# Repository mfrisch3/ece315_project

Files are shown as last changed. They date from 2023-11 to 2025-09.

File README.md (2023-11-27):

# PSoC&trade; 4: empty application template

This is a minimal starter application template for PSoC&trade; 4 devices.

[View this README on GitHub.](https://github.com/Infineon/mtb-example-psoc4-empty-app)

[Provide feedback on this code example.](https://cypress.co1.qualtrics.com/jfe/form/SV_1NTns53sK2yiljn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)

## Requirements

- [ModusToolbox&trade; software](https://www.cypress.com/products/modustoolbox-software-environment) v2.4 or later

  **Note:** This code example version requires ModusToolbox&trade; software version 2.4 or later and is not backward compatible with v2.3 or older versions.

- Board support package (BSP) minimum required version: 2.0.0
- Programming language: C
- Associated parts: [PSoC&trade; 4000S](https://www.cypress.com/documentation/datasheets/psoc-4-psoc-4000s-family-datasheet-programmable-system-chip-psoc), [PSoC&trade; 4100S](https://www.cypress.com/documentation/datasheets/psoc-4-psoc-4100s-family-datasheet-programmable-system-chip-psoc), [PSoC&trade; 4100S Plus](https://www.cypress.com/documentation/datasheets/psoc-4-psoc-4100s-plus-datasheet-programmable-system-chip-psoc), [PSoC&trade; 4500S](https://www.cypress.com/documentation/datasheets/psoc-4-psoc-4500s-datasheet-programmable-system-chip-psoc), and [PSoC&trade; 4100S Max](https://www.cypress.com/documentation/datasheets/psoc-4-psoc-4100s-max-datasheet-programmable-system-chip-psoc)

## Supported toolchains (make variable 'TOOLCHAIN')

- GNU Arm® embedded compiler v10.3.1 (`GCC_ARM`) - Default value of `TOOLCHAIN`
- Arm&reg; compiler v6.13 (`ARM`)
- IAR C/C++ compiler v8.42.2 (`IAR`)

## Supported kits (make variable 'TARGET')

- [PSoC&trade; 4100S Max pioneer kit](https://www.cypress.com/CY8CKIT-041s-max) (CY8CKIT-041S-MAX) - Default value of `TARGET`
- [PSoC&trade; 4100S Plus prototyping kit](https://www.cypress.com/CY8CKIT-149) (CY8CKIT-149)
- [PSoC&trade; 4100S CAPSENSE&trade; pioneer kit](https://www.cypress.com/CY8CKIT-041-41xx) (CY8CKIT-041-41XX)
- [PSoC&trade; 4000S CAPSENSE&trade; prototyping kit](https://www.cypress.com/CY8CKIT-145-40xx) (CY8CKIT-145-40XX)
- [PSoC&trade; 4500S pioneer kit](https://www.cypress.com/CY8CKIT-045S) (CY8CKIT-045S)

## Hardware setup

This example uses the board's default configuration. See the kit user guide to ensure that the board is configured correctly.

**Note:** The PSoC&trade; 4 kits ship with KitProg2 installed. The ModusToolbox&trade; software requires KitProg3. Before using this code example, make sure that the board is upgraded to KitProg3. The tool and instructions are available in the [Firmware Loader](https://github.com/Infineon/Firmware-loader) GitHub repository. If you do not upgrade, you will see an error like "unable to find CMSIS-DAP device" or "KitProg firmware is out of date".

## Software setup

This example requires no additional software or tools.
<br>

## Related resources

Resources  | Links
-----------|----------------------------------
Application notes | [AN79953](https://www.cypress.com/AN79953) – Getting started with PSoC&trade; 4
Code examples| [Using ModusToolbox&trade; software](https://github.com/Infineon/Code-Examples-for-ModusToolbox-Software) on GitHub <br> [Using PSoC&trade; Creator](https://www.cypress.com/documentation/code-examples/psoc-345-code-examples)
Device documentation | [PSoC&trade; 4 datasheets](https://www.cypress.com/search/all/PSOC%204%20datasheets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) <br>[PSoC&trade; 4 technical reference manuals](https://www.cypress.com/search/all/PSoC%204%20Technical%20Reference%20Manual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)
Development kits | Visit www.cypress.com/microcontrollers-mcus-kits and use the options in the **Select your kit** section to filter kits by *Product family* or *Features*.
Libraries on GitHub | [mtb-pdl-cat2](https://github.com/Infineon/mtb-pdl-cat2) – PSoC&trade; 4 peripheral driver library (PDL)<br> [mtb-hal-cat2](https://github.com/Infineon/mtb-hal-cat2) – Hardware abstraction layer (HAL) library
Tools  | [Eclipse IDE for ModusToolbox&trade; software](https://www.cypress.com/modustoolbox) – ModusToolbox&trade; software is a collection of easy-to-use software and tools enabling rapid development with Infineon MCUs, covering applications from embedded sense and control to wireless and cloud-connected systems using AIROC&trade; Wi-Fi and Bluetooth® connectivity devices. <br> [PSoC&trade; Creator](https://www.cypress.com/products/psoc-creator-integrated-design-environment-ide) – IDE for PSoC&trade; and FM0+ MCU development

<br>

## Other resources

Cypress provides a wealth of data at www.cypress.com to help you select the right device, and quickly and effectively integrate it into your design.

## Document history

Document title: *CE230705 - PSoC&trade; 4: empty application template*

Version | Description of change
------- | ---------------------
 1.0.0   | New code example
 2.0.0   | Major update to support ModusToolbox&trade; software v2.2, added support for new kits<br> This version is not backward compatible with ModusToolbox&trade; software v2.1
 2.1.0   | Added support for new kits

<br>

---------------------------------------------------------

© Cypress Semiconductor Corporation, 2020-2021. This document is the property of Cypress Semiconductor Corporation, an Infineon Technologies company, and its affiliates ("Cypress").  This document, including any software or firmware included or referenced in this document ("Software"), is owned by Cypress under the intellectual property laws and treaties of the United States and other countries worldwide.  Cypress reserves all rights under such laws and treaties and does not, except as specifically stated in this paragraph, grant any license under its patents, copyrights, trademarks, or other intellectual property rights.  If the Software is not accompanied by a license agreement and you do not otherwise have a written agreement with Cypress governing the use of the Software, then Cypress hereby grants you a personal, non-exclusive, nontransferable license (without the right to sublicense) (1) under its copyright rights in the Software (a) for Software provided in source code form, to modify and reproduce the Software solely for use with Cypress hardware products, only internally within your organization, and (b) to distribute the Software in binary code form externally to end users (either directly or indirectly through resellers and distributors), solely for use on Cypress hardware product units, and (2) under those claims of Cypress’s patents that are infringed by the Software (as provided by Cypress, unmodified) to make, use, distribute, and import the Software solely for use with Cypress hardware products.  Any other use, reproduction, modification, translation, or compilation of the Software is prohibited.
<br>
TO THE EXTENT PERMITTED BY APPLICABLE LAW, CYPRESS MAKES NO WARRANTY OF ANY KIND, EXPRESS OR IMPLIED, WITH REGARD TO THIS DOCUMENT OR ANY SOFTWARE OR ACCOMPANYING HARDWARE, INCLUDING, BUT NOT LIMITED TO, THE IMPLIED WARRANTIES OF MERCHANTABILITY AND FITNESS FOR A PARTICULAR PURPOSE.  No computing device can be absolutely secure.  Therefore, despite security measures implemented in Cypress hardware or software products, Cypress shall have no liability arising out of any security breach, such as unauthorized access to or use of a Cypress product. CYPRESS DOES NOT REPRESENT, WARRANT, OR GUARANTEE THAT CYPRESS PRODUCTS, OR SYSTEMS CREATED USING CYPRESS PRODUCTS, WILL BE FREE FROM CORRUPTION, ATTACK, VIRUSES, INTERFERENCE, HACKING, DATA LOSS OR THEFT, OR OTHER SECURITY INTRUSION (collectively, "Security Breach").  Cypress disclaims any liability relating to any Security Breach, and you shall and hereby do release Cypress from any claim, damage, or other liability arising from any Security Breach.  In addition, the products described in these materials may contain design defects or errors known as errata which may cause the product to deviate from published specifications. To the extent permitted by applicable law, Cypress reserves the right to make changes to this document without further notice. Cypress does not assume any liability arising out of the application or use of any product or circuit described in this document. Any information provided in this document, including any sample design information or programming code, is provided only for reference purposes.  It is the responsibility of the user of this document to properly design, program, and test the functionality and safety of any application made of this information and any resulting product.  "High-Risk Device" means any device or system whose failure could cause personal injury, death, or property damage.  Examples of High-Risk Devices are weapons, nuclear installations, surgical implants, and other medical devices.  "Critical Component" means any component of a High-Risk Device whose failure to perform can be reasonably expected to cause, directly or indirectly, the failure of the High-Risk Device, or to affect its safety or effectiveness.  Cypress is not liable, in whole or in part, and you shall and hereby do release Cypress from any claim, damage, or other liability arising from any use of a Cypress product as a Critical Component in a High-Risk Device. You shall indemnify and hold Cypress, including its affiliates, and its directors, officers, employees, agents, distributors, and assigns harmless from and against all claims, costs, damages, and expenses, arising out of any claim, including claims for product liability, personal injury or death, or property damage arising from any use of a Cypress product as a Critical Component in a High-Risk Device. Cypress products are not intended or authorized for use as a Critical Component in any High-Risk Device except to the limited extent that (i) Cypress’s published data sheet for the product explicitly states Cypress has qualified the product for use in a specific High-Risk Device, or (ii) Cypress has given you advance written authorization to use the product as a Critical Component in the specific High-Risk Device and you have signed a separate indemnification agreement.
<br>
Cypress, the Cypress logo, and combinations thereof, WICED, ModusToolbox, PSoC, CapSense, EZ-USB, F-RAM, and Traveo are trademarks or registered trademarks of Cypress or a subsidiary of Cypress in the United States or in other countries. For a more complete list of Cypress trademarks, visit cypress.com. Other names and brands may be claimed as property of their respective owners.

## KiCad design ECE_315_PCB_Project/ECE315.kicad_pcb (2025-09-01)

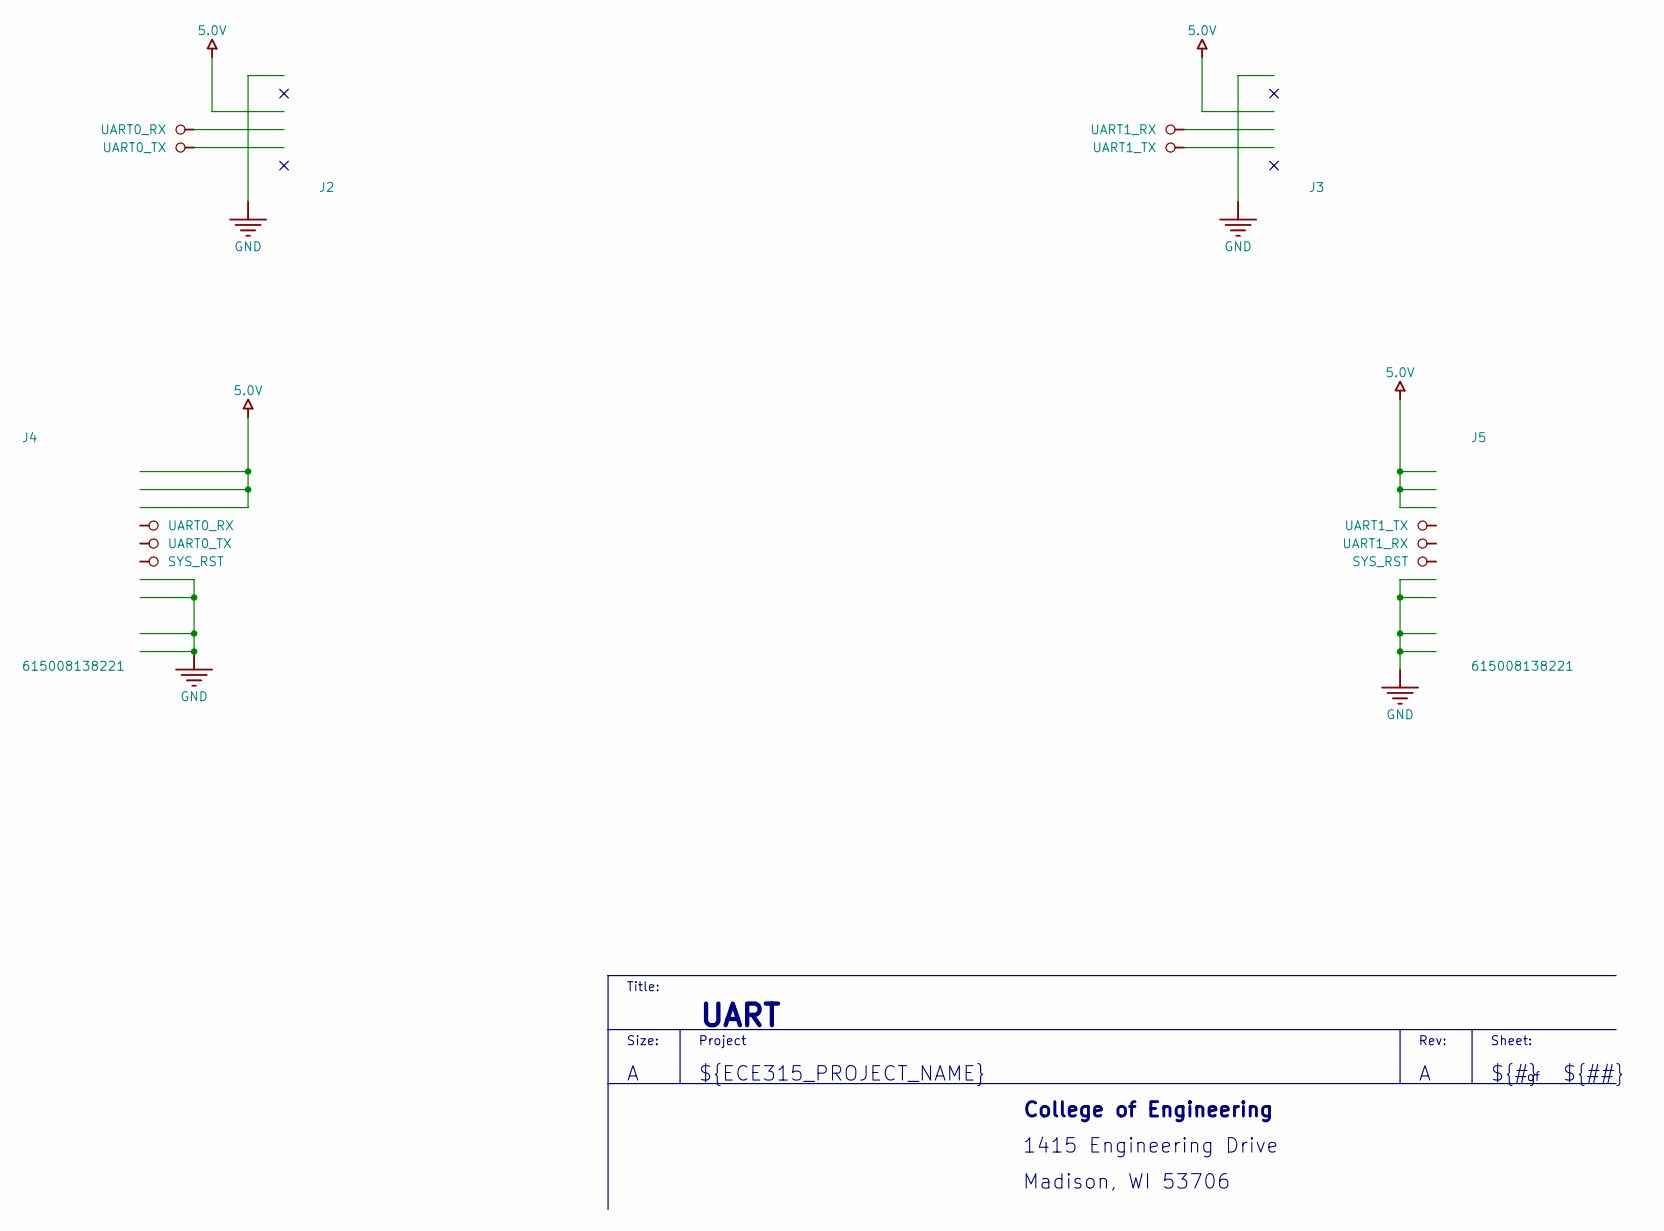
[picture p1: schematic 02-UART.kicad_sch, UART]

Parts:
J2, J3: HDR1X6; VOLTAGE RATING 250V; FLAMMABILITY RATING UL94 V-0; MANUFACTURER PART NUMBE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 PPPC061LGBN-RC
J4, J5: 615008138221; WITHSTANDING VOLTAGE 1000VAC; WORKING VOLTAGE 120VAC; PART NUMBER 615008138221

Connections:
5.0V: J2.3, J3.3, J4.1, J4.2, J4.3, J5.1, J5.2, J5.3; also elsewhere on the board
GND: J2.1, J3.1, J4.7, J4.8, J4.S1, J4.S2, J5.7, J5.8, J5.S1, J5.S2; also elsewhere on the board
SYS_RST: J4.6, J5.6; also elsewhere on the board
UART0_RX: J2.4, J4.4; also elsewhere on the board
UART0_TX: J2.5, J4.5; also elsewhere on the board
UART1_RX: J3.4, J5.5; also elsewhere on the board
UART1_TX: J3.5, J5.4; also elsewhere on the board

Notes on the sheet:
Rev:
Sheet:
${REVISION}
Size:
${TITLE}
${#}
Project
College of Engineering
Title:
${ECE315_PROJECT_NAME}
1415 Engineering Drive
Madison, WI 53706
${##}

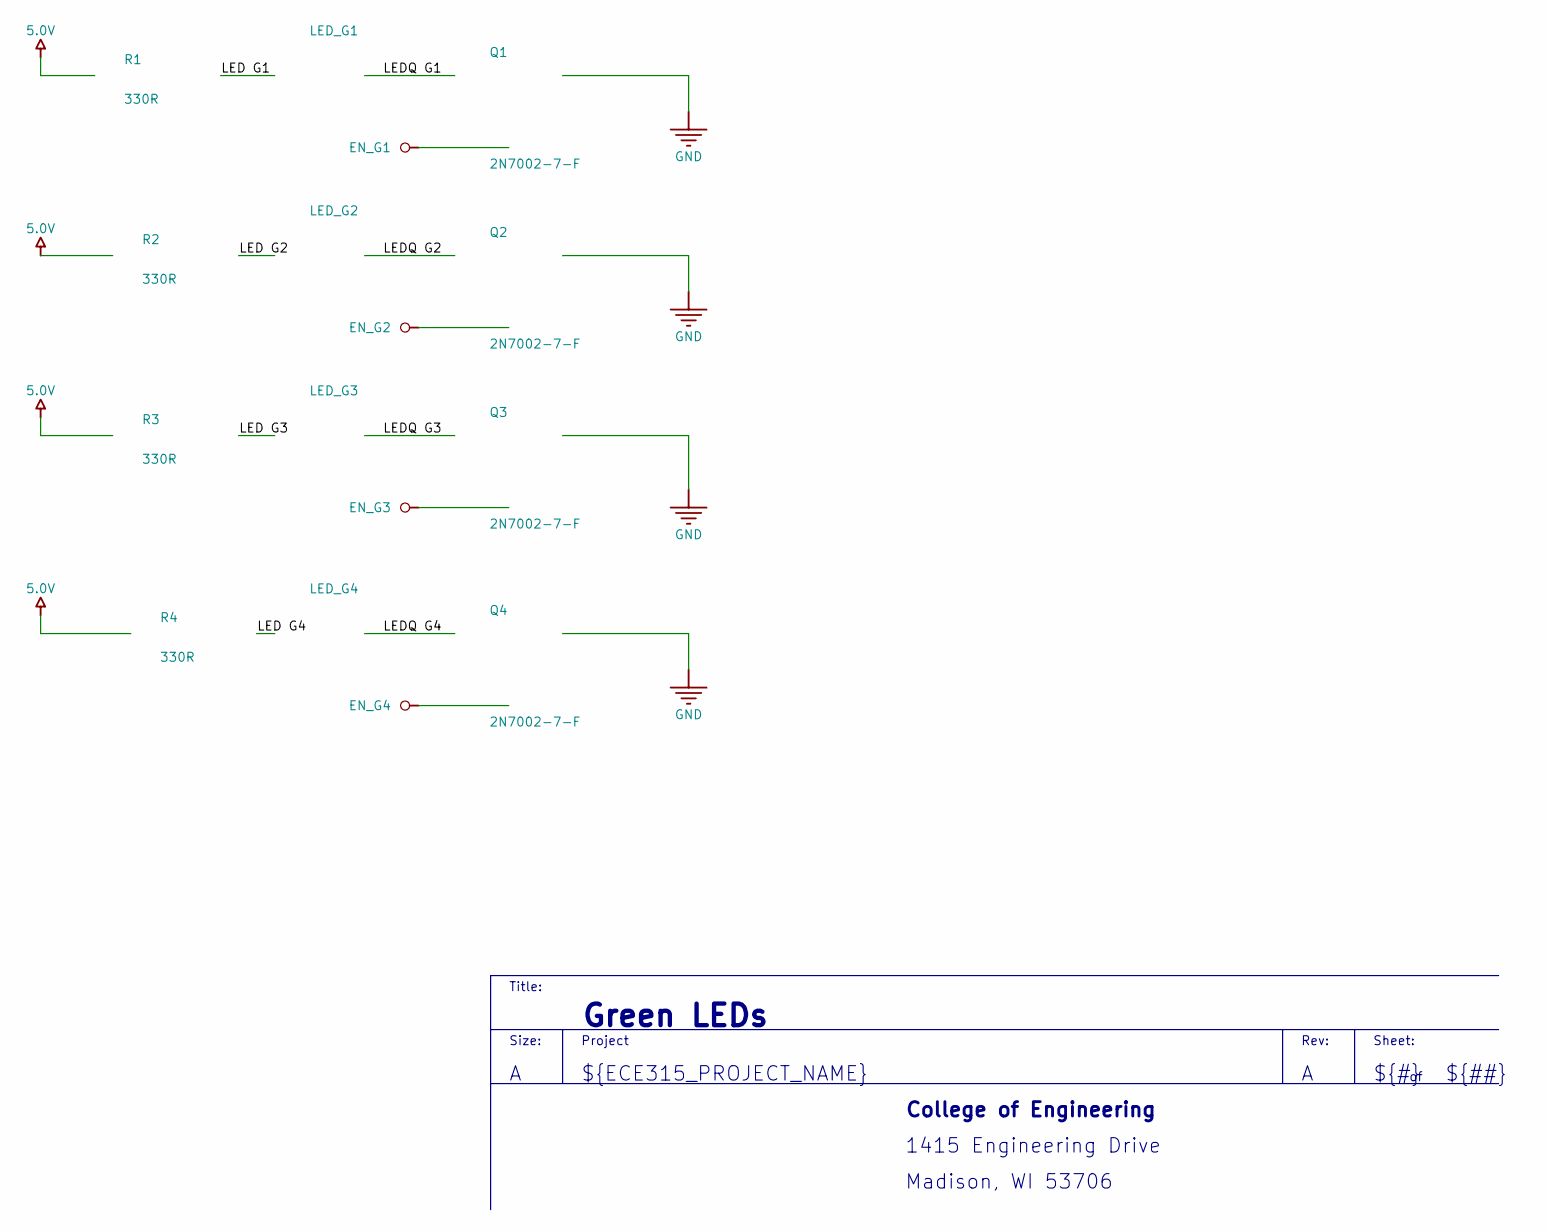
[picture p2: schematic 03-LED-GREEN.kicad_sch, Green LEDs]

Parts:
LED_G1, LED_G2, LED_G3, LED_G4: 150120GS75000; WL-SMCW_1206_150120xx75000; REVERSE VOLTAGE 5V; FORWARD VOLTAGE 3.2V; MANUFACTURER PART NUMBER 150120GS75000
Q1, Q2, Q3, Q4: 2N7002-7-F; FP-SOT23-MFG; CURRENT RATING 115mA; VOLTAGE RATING (DC) 60V
R1, R2, R3, R4: 330R; FP-CRCW1206-e3-IPC_A; VOLTAGE RATING 200V; VOLTAGE RATING (DC) 200V

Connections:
5.0V: R1.1, R2.1, R3.1, R4.1; also elsewhere on the board
EN_G1: Q1.1 (G); also elsewhere on the board
EN_G2: Q2.1 (G); also elsewhere on the board
EN_G3: Q3.1 (G); also elsewhere on the board
EN_G4: Q4.1 (G); also elsewhere on the board
GND: Q1.2 (S), Q2.2 (S), Q3.2 (S), Q4.2 (S); also elsewhere on the board
LED G1: LED_G1.2 (A), R1.2
LED G2: LED_G2.2 (A), R2.2
LED G3: LED_G3.2 (A), R3.2
LED G4: LED_G4.2 (A), R4.2
LEDQ G1: LED_G1.1 (K), Q1.3 (D)
LEDQ G2: LED_G2.1 (K), Q2.3 (D)
LEDQ G3: LED_G3.1 (K), Q3.3 (D)
LEDQ G4: LED_G4.1 (K), Q4.3 (D)

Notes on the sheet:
${ECE315_PROJECT_NAME}
College of Engineering
${TITLE}
Size:
${##}
${#}
Rev:
1415 Engineering Drive
Madison, WI 53706
Sheet:
${REVISION}
Title:
Project

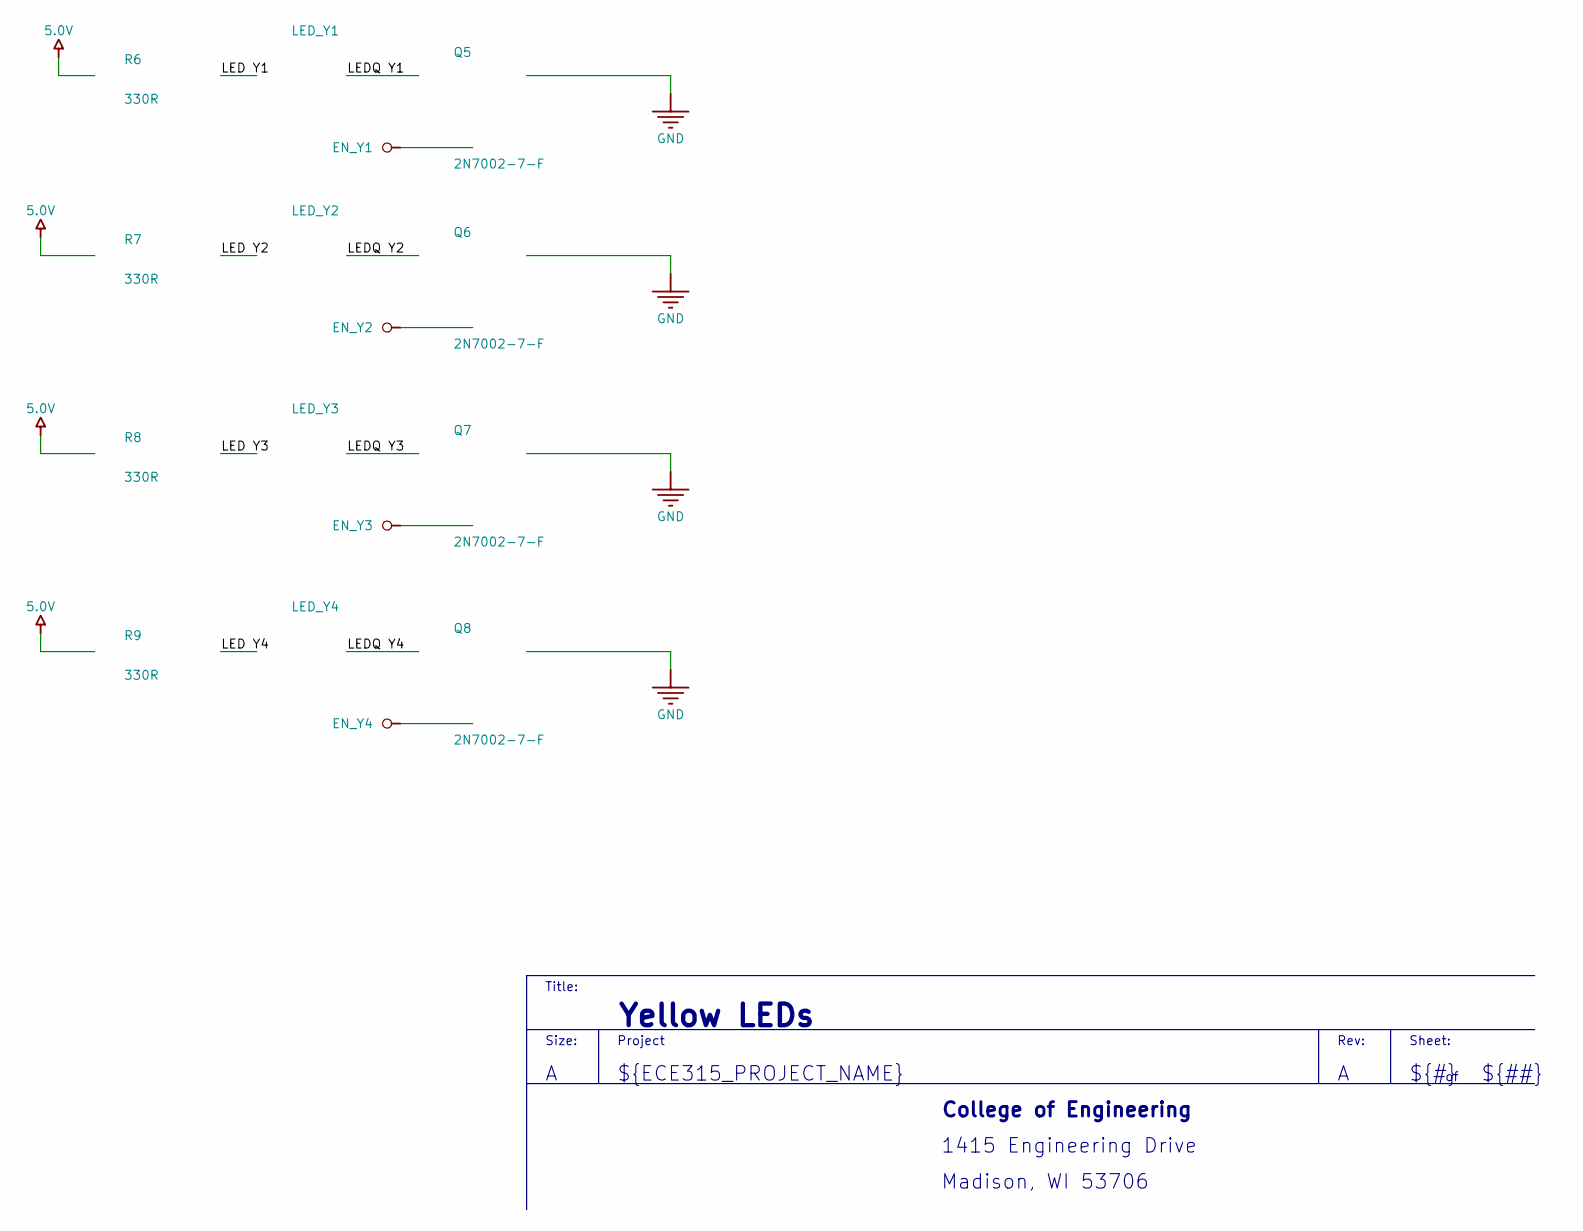
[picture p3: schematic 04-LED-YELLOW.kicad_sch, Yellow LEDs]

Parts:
LED_Y1, LED_Y2, LED_Y3, LED_Y4: SML-LX1206YC-TR; LUMX-SML-LX1206YC-TR_V; MILLICANDELA RATING 6mcd; VOLTAGE - FORWARD (VF) 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 2.1V; MANUFACTURER PART NUMBE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 SML-LX1206YC-TR
Q5, Q6, Q7, Q8: 2N7002-7-F; FP-SOT23-MFG; CURRENT RATING 115mA; VOLTAGE RATING (DC) 60V
R6, R7, R8, R9: 330R; FP-CRCW1206-e3-IPC_A; VOLTAGE RATING 200V; VOLTAGE RATING (DC) 200V

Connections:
5.0V: R6.1, R7.1, R8.1, R9.1; also elsewhere on the board
EN_Y1: Q5.1 (G); also elsewhere on the board
EN_Y2: Q6.1 (G); also elsewhere on the board
EN_Y3: Q7.1 (G); also elsewhere on the board
EN_Y4: Q8.1 (G); also elsewhere on the board
GND: Q5.2 (S), Q6.2 (S), Q7.2 (S), Q8.2 (S); also elsewhere on the board
LED Y1: LED_Y1.1 (A), R6.2
LED Y2: LED_Y2.1 (A), R7.2
LED Y3: LED_Y3.1 (A), R8.2
LED Y4: LED_Y4.1 (A), R9.2
LEDQ Y1: LED_Y1.2 (K), Q5.3 (D)
LEDQ Y2: LED_Y2.2 (K), Q6.3 (D)
LEDQ Y3: LED_Y3.2 (K), Q7.3 (D)
LEDQ Y4: LED_Y4.2 (K), Q8.3 (D)

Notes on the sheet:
Title:
Madison, WI 53706
Sheet:
${TITLE}
Size:
College of Engineering
Project
${ECE315_PROJECT_NAME}
1415 Engineering Drive
${#}
${##}
Rev:
${REVISION}

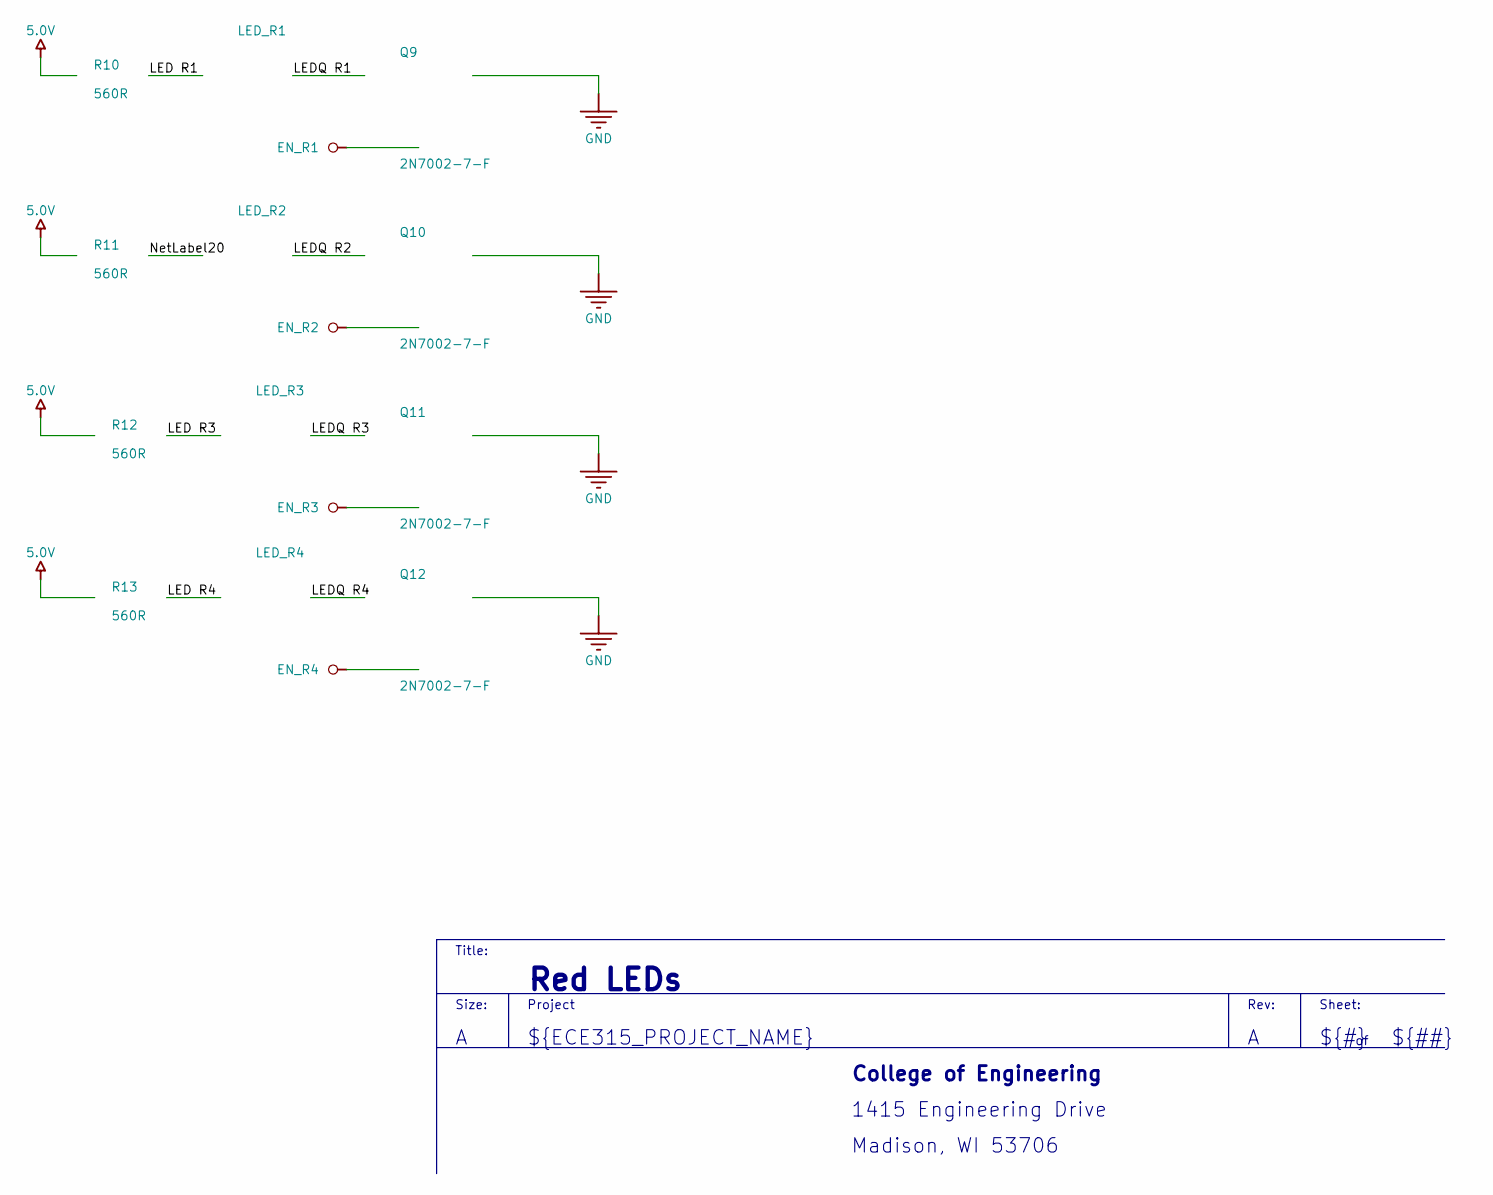
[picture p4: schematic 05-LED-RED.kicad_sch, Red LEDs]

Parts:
LED_R1, LED_R2, LED_R3, LED_R4: SML-LX1206IC-TR; LUMX-SML-LX1206IC_V; REVERSE VOLTAGE 5(Min)V; FORWARD VOLTAGE 2.6V; PART NO SML-LX1206IC-TR
Q9, Q10, Q11, Q12: 2N7002-7-F; FP-SOT23-MFG; CURRENT RATING 115mA; VOLTAGE RATING (DC) 60V
R10, R11, R12, R13: 560R; RESC3216X70X50LL05T20; PART NUMBER ERJ8ENF5600V

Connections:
5.0V: R10.1, R11.1, R12.1, R13.1; also elsewhere on the board
EN_R1: Q9.1 (G); also elsewhere on the board
EN_R2: Q10.1 (G); also elsewhere on the board
EN_R3: Q11.1 (G); also elsewhere on the board
EN_R4: Q12.1 (G); also elsewhere on the board
GND: Q9.2 (S), Q10.2 (S), Q11.2 (S), Q12.2 (S); also elsewhere on the board
LED R1: LED_R1.1 (A), R10.2
LED R3: LED_R3.1 (A), R12.2
LED R4: LED_R4.1 (A), R13.2
LEDQ R1: LED_R1.2 (K), Q9.3 (D)
LEDQ R2: LED_R2.2 (K), Q10.3 (D)
LEDQ R3: LED_R3.2 (K), Q11.3 (D)
LEDQ R4: LED_R4.2 (K), Q12.3 (D)
NetLabel20: LED_R2.1 (A), R11.2

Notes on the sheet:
${##}
Rev:
${TITLE}
${ECE315_PROJECT_NAME}
Title:
${REVISION}
${#}
College of Engineering
Project
Madison, WI 53706
Sheet:
1415 Engineering Drive
Size:

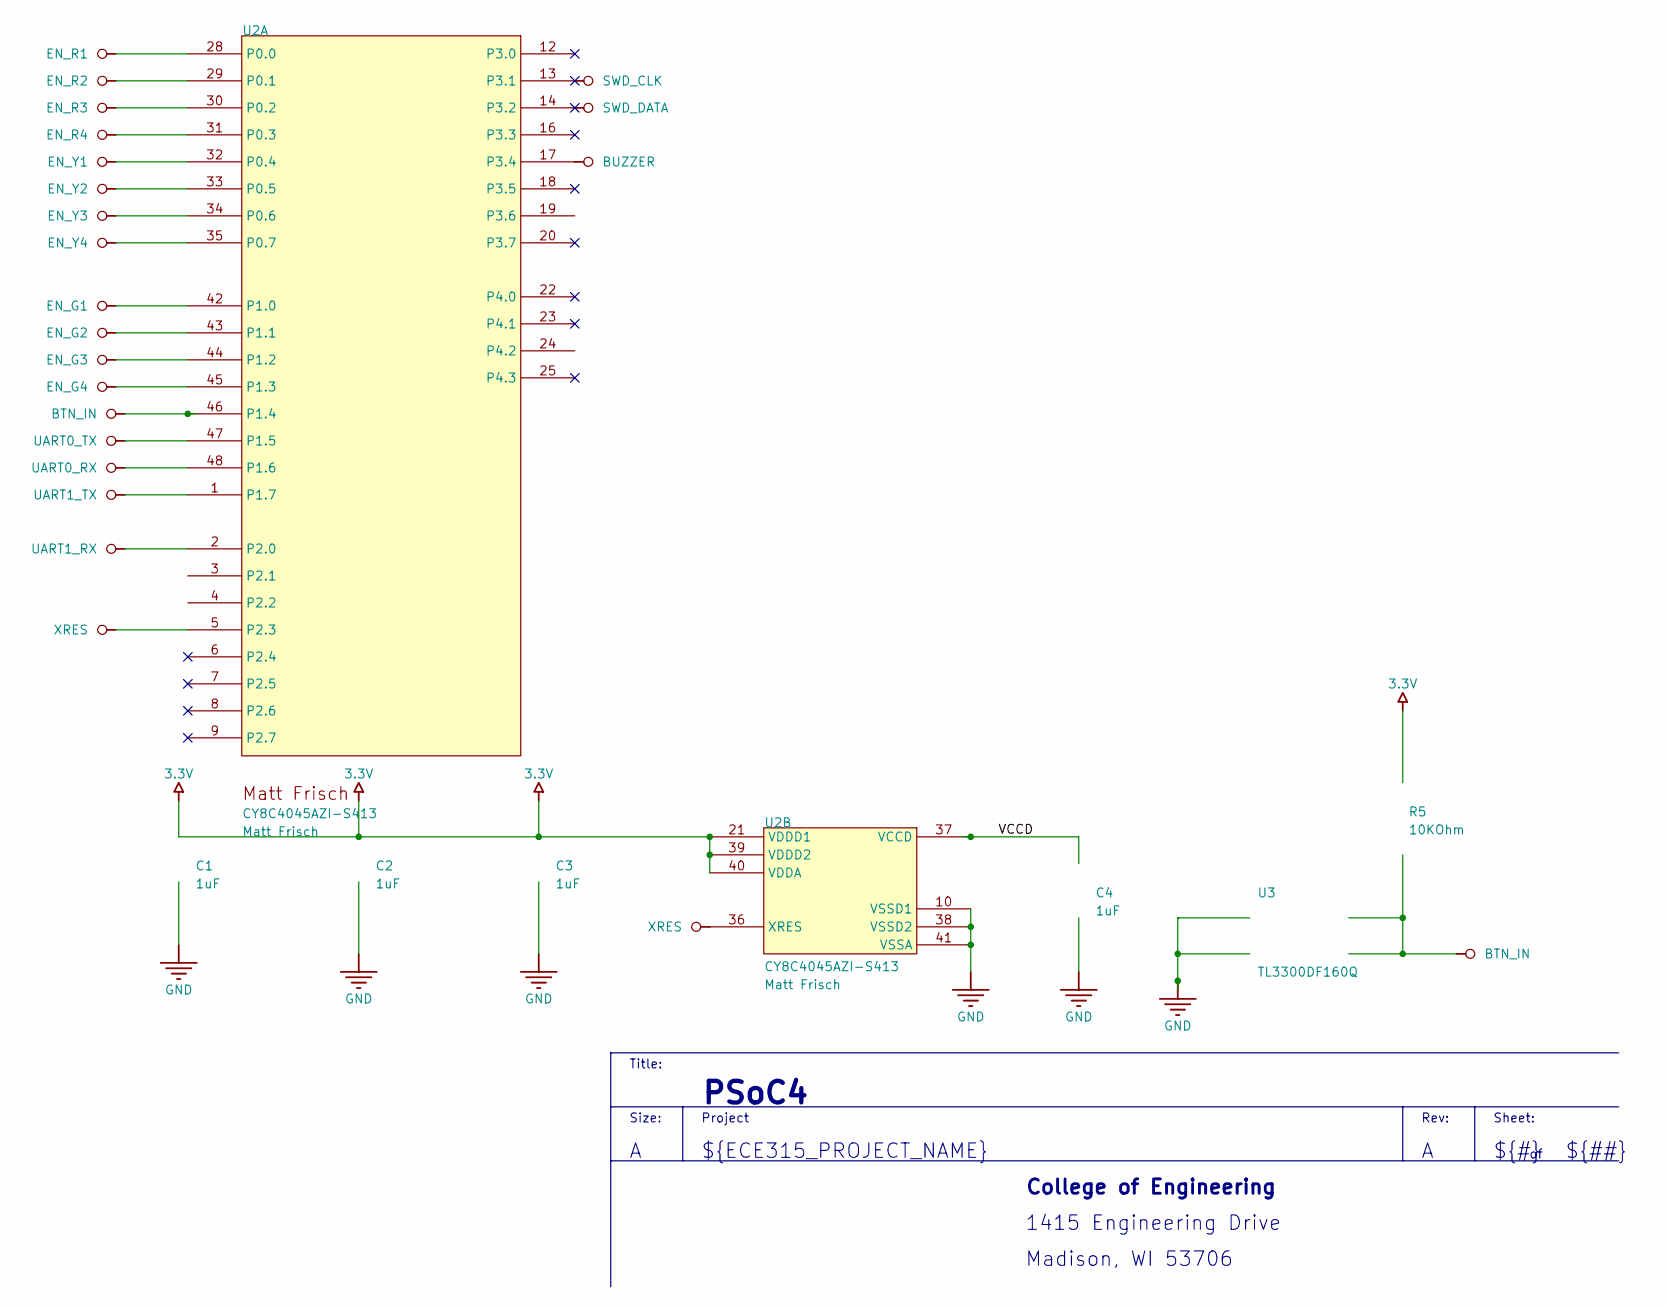
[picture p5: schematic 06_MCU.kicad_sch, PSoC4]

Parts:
C1, C2, C3, C4: 1uF; CAPC3216X180X50ML20T25; VOLTAGE RATING DC 25V; TOLERANCE 10%
R5: 10KOhm; RESC3116X65X40ML10T20; TOLERANCE 1%; VOLTAGE RATING 200V
U2: CY8C4045AZI-S413; TQFP48_7X7; MANUFACTURER PART NUMBE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 CY8C4045AZI-S413
U3: TL3300DF160Q; CONTACT RATING @ VOLTAGE 0.05A @ 12VDC; CURRENT RATING 50mA; MANUFACTURER PART NUMBER TL3300DF160Q

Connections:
3.3V: C1.2, C2.2, C3.2, R5.1, U2.21 (VDDD1), U2.39 (VDDD2), U2.40 (VDDA); also elsewhere on the board
BTN_IN: R5.2, U2.46 (P1.4), U3.3, U3.4 (VCCIO)
BUZZER: U2.17 (P3.4); also elsewhere on the board
EN_G1: U2.42 (P1.0); also elsewhere on the board
EN_G2: U2.43 (P1.1); also elsewhere on the board
EN_G3: U2.44 (P1.2); also elsewhere on the board
EN_G4: U2.45 (P1.3); also elsewhere on the board
EN_R1: U2.28 (P0.0); also elsewhere on the board
EN_R2: U2.29 (P0.1); also elsewhere on the board
EN_R3: U2.30 (P0.2); also elsewhere on the board
EN_R4: U2.31 (P0.3); also elsewhere on the board
EN_Y1: U2.32 (P0.4); also elsewhere on the board
EN_Y2: U2.33 (P0.5); also elsewhere on the board
EN_Y3: U2.34 (P0.6); also elsewhere on the board
EN_Y4: U2.35 (P0.7); also elsewhere on the board
GND: C1.1, C2.1, C3.1, C4.1, U2.10 (VSSD1), U2.38 (VSSD2), U2.41 (VSSA), U3.1, U3.2; also elsewhere on the board
SWD_CLK: U2.3 (P2.1); also elsewhere on the board
SWD_DATA: U2.4 (P2.2); also elsewhere on the board
UART0_RX: U2.48 (P1.6); also elsewhere on the board
UART0_TX: U2.47 (P1.5); also elsewhere on the board
UART1_RX: U2.2 (P2.0); also elsewhere on the board
UART1_TX: U2.1 (P1.7); also elsewhere on the board
VCCD: C4.2, U2.37 (VCCD)
XRES: U2.5 (P2.3), U2.36 (XRES); also elsewhere on the board

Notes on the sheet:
${TITLE}
Madison, WI 53706
${##}
Project
1415 Engineering Drive
Sheet:
${ECE315_PROJECT_NAME}
Size:
College of Engineering
Title:
Rev:
${REVISION}
${#}

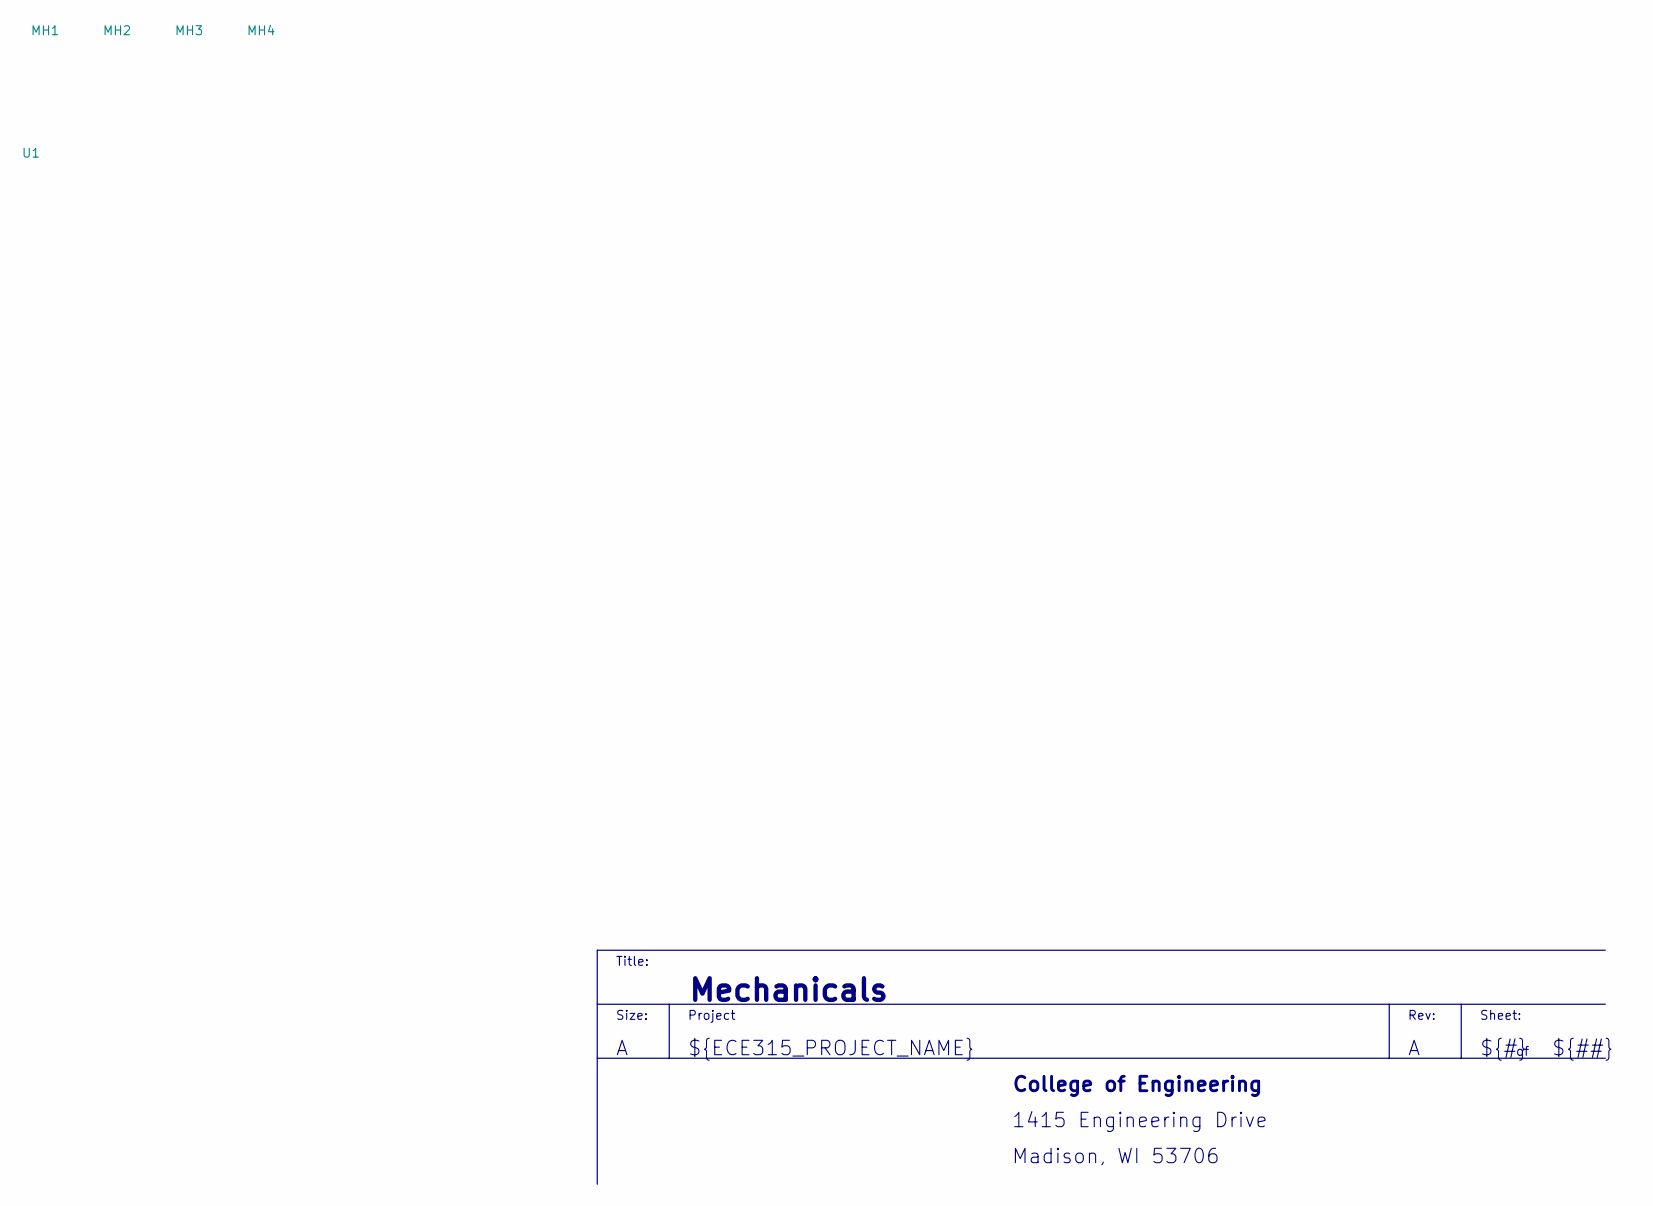
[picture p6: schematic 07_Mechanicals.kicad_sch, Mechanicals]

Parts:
MH1, MH2, MH3, MH4: MHOLE_2_55MM; MANUFACTURER PART NUMBER UW MTHOLE
U1: Bucky; WalkingBucky; MANUFACTURER PART NUMBER UW Bucky

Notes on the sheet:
${REVISION}
Rev:
Project
${TITLE}
${#}
College of Engineering
Title:
1415 Engineering Drive
${ECE315_PROJECT_NAME}
Sheet:
Madison, WI 53706
Size:
${##}

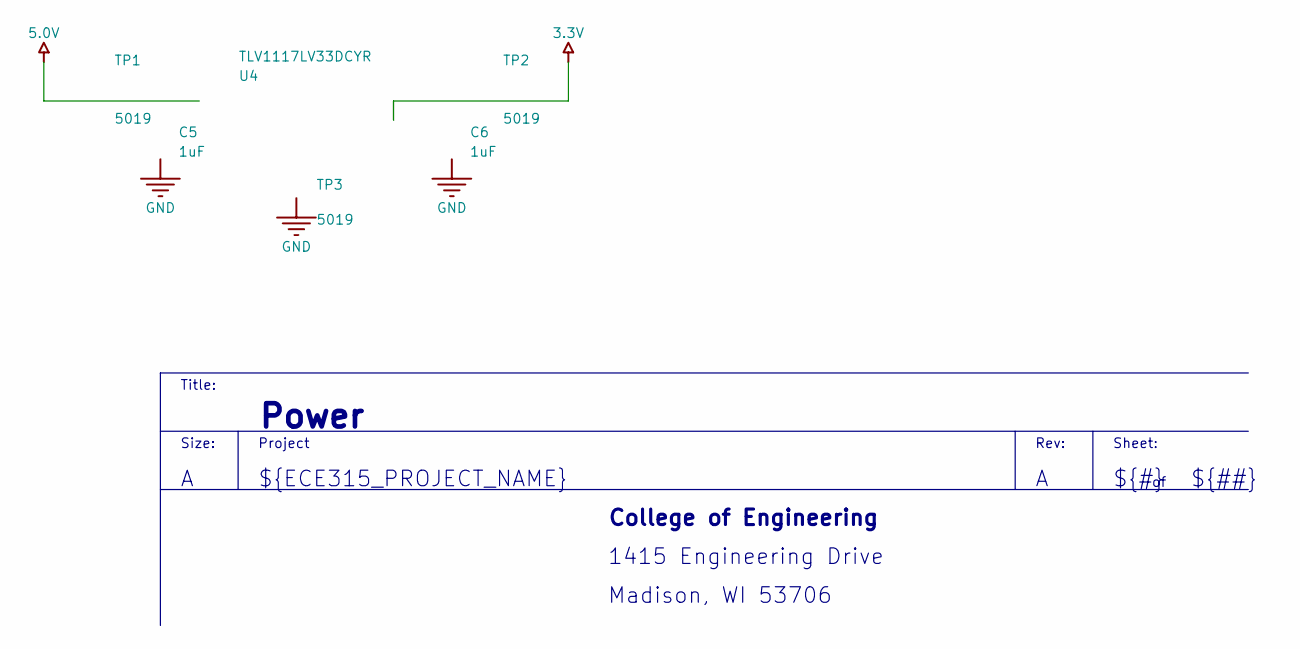
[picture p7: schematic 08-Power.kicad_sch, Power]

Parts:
C5, C6: 1uF; CAPC3216X180X50ML20T25; VOLTAGE RATING DC 25V; TOLERANCE 10%
TP1, TP2, TP3: 5019; KSTN-5019_V
U4: TLV1117LV33DCYR; DCY0004A_N; PARTNUMBER TLV1117LV33DCYR

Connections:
3.3V: C6.2, TP2.1, U4.2 (OUT), U4.4 (OUT); also elsewhere on the board
5.0V: C5.2, TP1.1, U4.3 (IN); also elsewhere on the board
GND: C5.1, C6.1, TP3.1, U4.1 (GND); also elsewhere on the board

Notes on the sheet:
Title:
${ECE315_PROJECT_NAME}
${REVISION}
${#}
Rev:
Sheet:
${##}
${TITLE}
College of Engineering
Size:
Madison, WI 53706
Project
1415 Engineering Drive

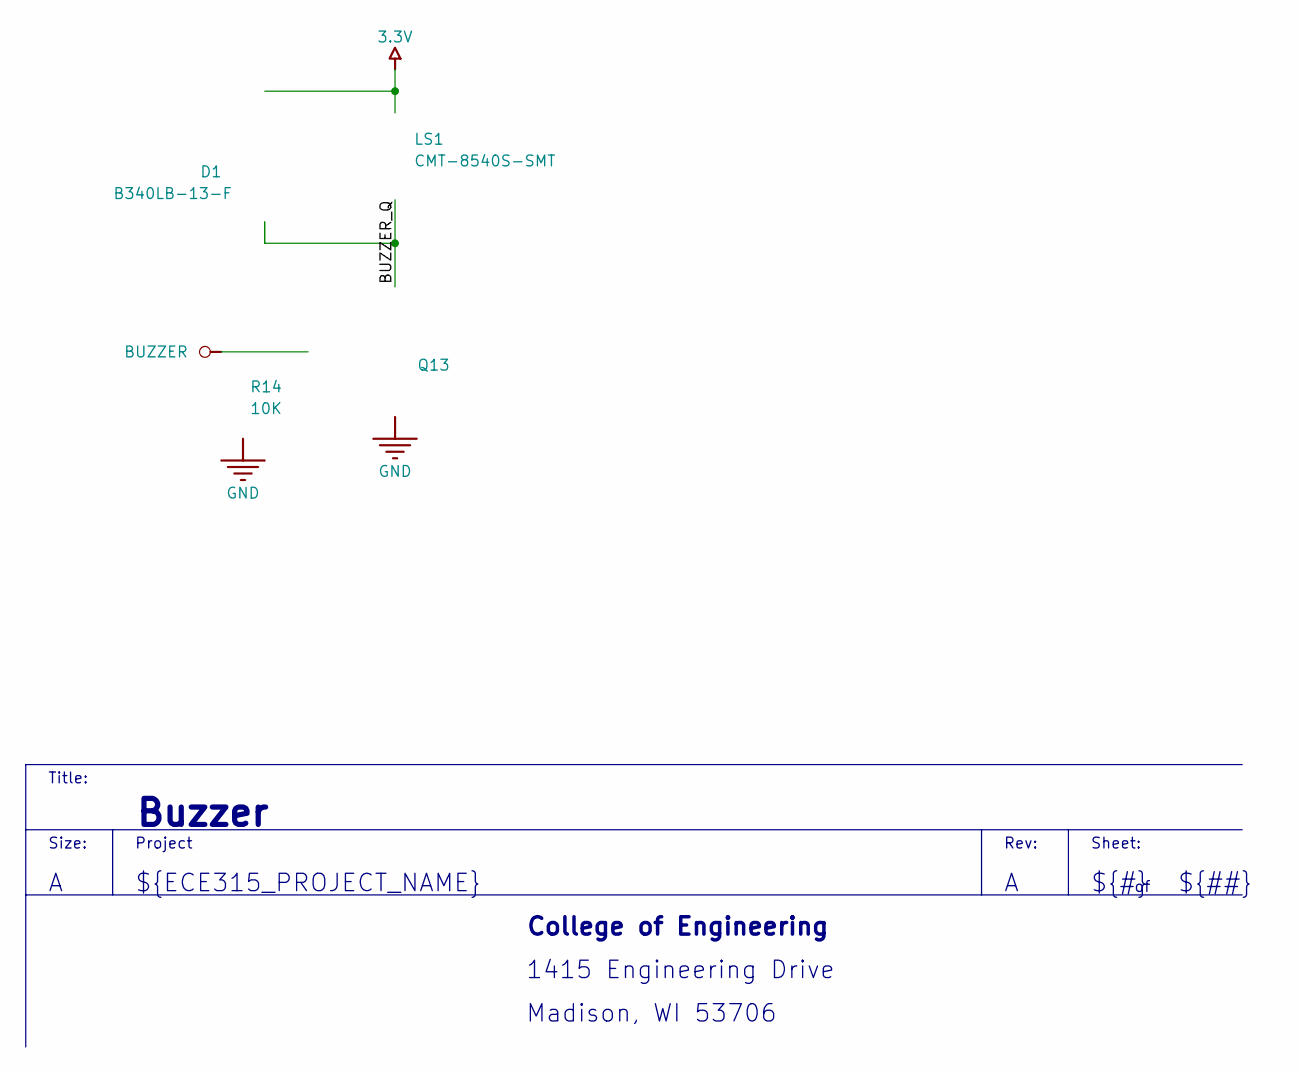
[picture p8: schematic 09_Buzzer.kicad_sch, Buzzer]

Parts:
D1: B340LB-13-F; FP-SMB-MFG; REVERSE VOLTAGE 40V; FORWARD VOLTAGE 450mV; MANUFACTURER PART NUMBER B340LB-13-F; DIGIKEY DESCRIPTION DIODE SCHOTTKY 40V 3A SMB
LS1: CMT-8540S-SMT; CUI_CMT-8540S-SMT; VOLTAGE RATING 5V; MANUFACTURER PART NUMBE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 CMT-8540S-SMT-TR
Q13: 2N7002-7-F; FP-SOT23-MFG; CURRENT RATING 115mA; VOLTAGE RATING (DC) 60V; MANUFACTURER PART NUMBE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 2N7002-7-F
R14: RC1206FR-0710KL; RESC3116X65X40ML10T20; TOLERANCE 1%; VOLTAGE RATING 200V; MANUFACTURER PART NUMBER RC1206FR-0710KL

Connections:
3.3V: D1.1 (C), LS1.P; also elsewhere on the board
BUZZER: Q13.1 (G), R14.2; also elsewhere on the board
BUZZER_Q: D1.2 (A), LS1.N, Q13.3 (D)
GND: Q13.2 (S), R14.1; also elsewhere on the board

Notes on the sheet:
${REVISION}
${TITLE}
Size:
Sheet:
Title:
${##}
Rev:
College of Engineering
${#}
1415 Engineering Drive
Madison, WI 53706
Project
${ECE315_PROJECT_NAME}

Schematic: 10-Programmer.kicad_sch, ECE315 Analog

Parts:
J1: 10129380-905002BLF; AMPHENOL_10129380-905002BLF; MANUFACTURER PART NUMBE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 10129380-905002BLF
R15, R16: RC1206FR-0710KL; RESC3116X65X40ML10T20; TOLERANCE 1%; VOLTAGE RATING 200V; MANUFACTURER PART NUMBER RC1206FR-0710KL
SW1: B3U-1000P; FP-B3U-1000P-MFG; MAX VOLTAGE RATING (DC) 12V; CURRENT RATING 50mA; MANUFACTURER PART NUMBER B3U-1000P
U5: SN74AHC1G08DBVR; FP-DBV0005A-MFG; MANUFACTURER PART NUMBER SN74AHC1G08DBVR; DIGIKEY DESCRIPTION IC GATE AND 1CH 2-INP SOT23-5

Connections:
3.3V: J1.5, R15.2, R16.2, U5.5 (VCC); also elsewhere on the board
GND: J1.4, SW1.1, U5.3 (GND); also elsewhere on the board
MCU_RST: J1.3, R16.1, SW1.2, U5.2 (B)
SWD_CLK: J1.2; also elsewhere on the board
SWD_DATA: J1.1; also elsewhere on the board
SYS_RST: R15.1, U5.1 (A); also elsewhere on the board
XRES: U5.4 (Y); also elsewhere on the board

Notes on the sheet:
Madison, WI 53706
Project
${##}
${#}
1415 Engineering Drive
Title:
Rev:
${ECE315_PROJECT_NAME}
Size:
College of Engineering
${TITLE}
${REVISION}
Sheet:
5 Pin MiniProg4 Header
Push button reset for MCU

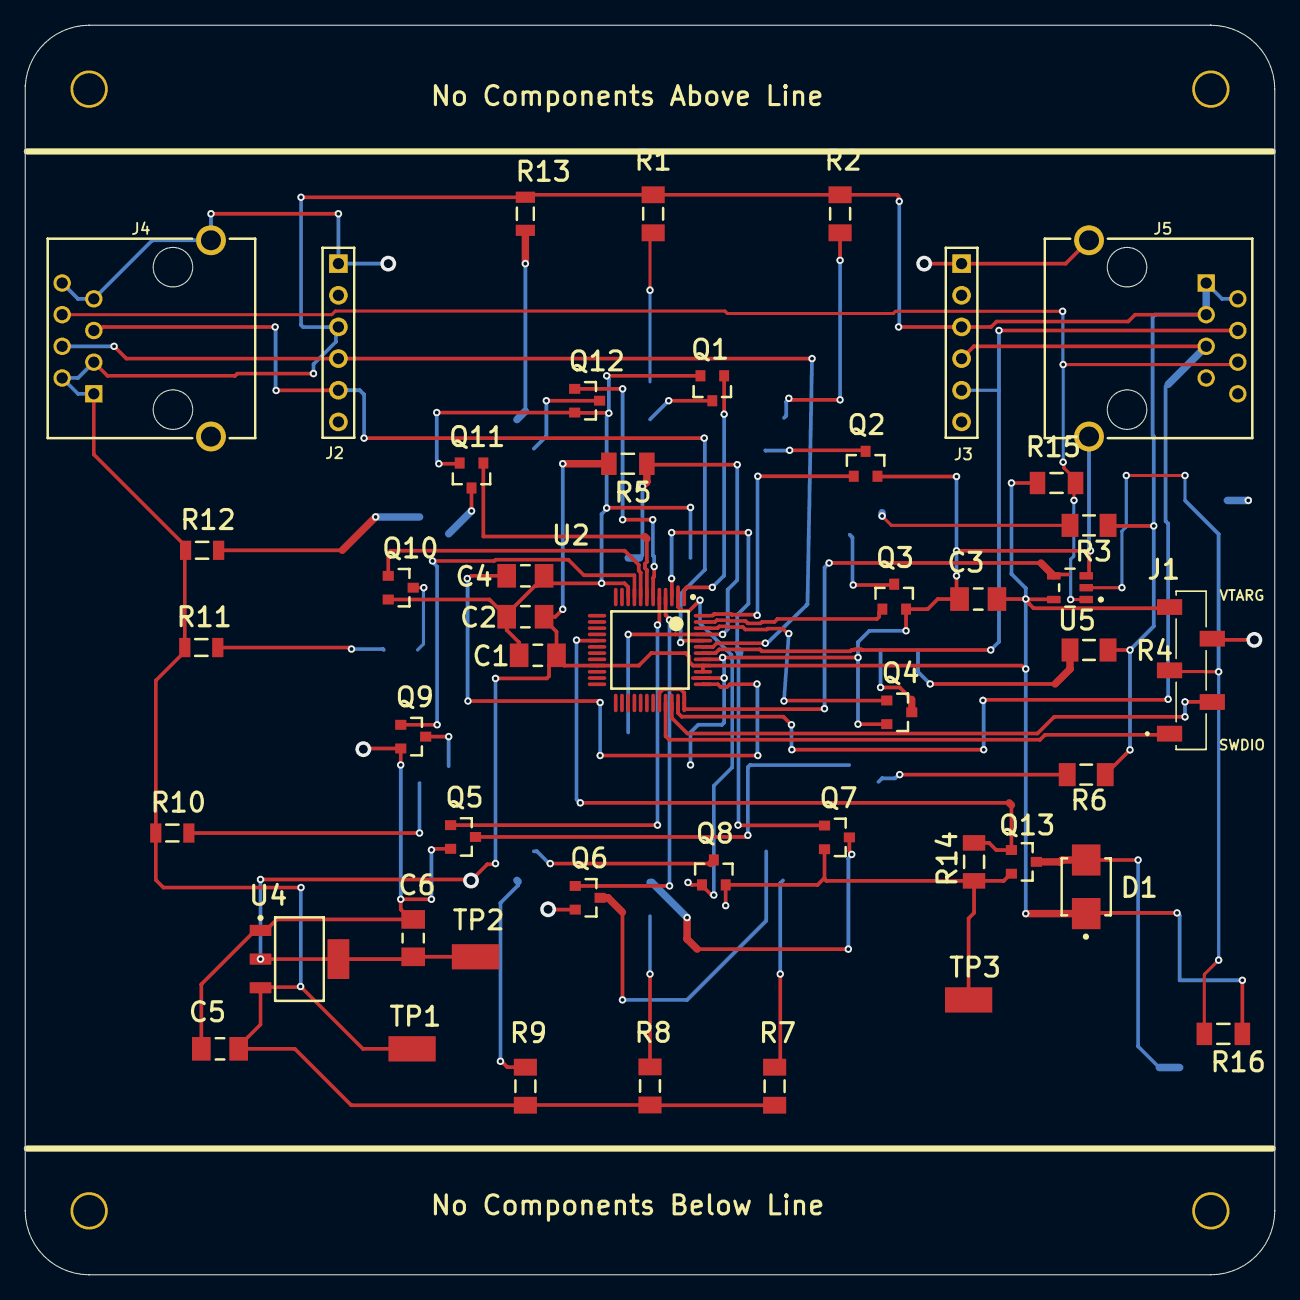
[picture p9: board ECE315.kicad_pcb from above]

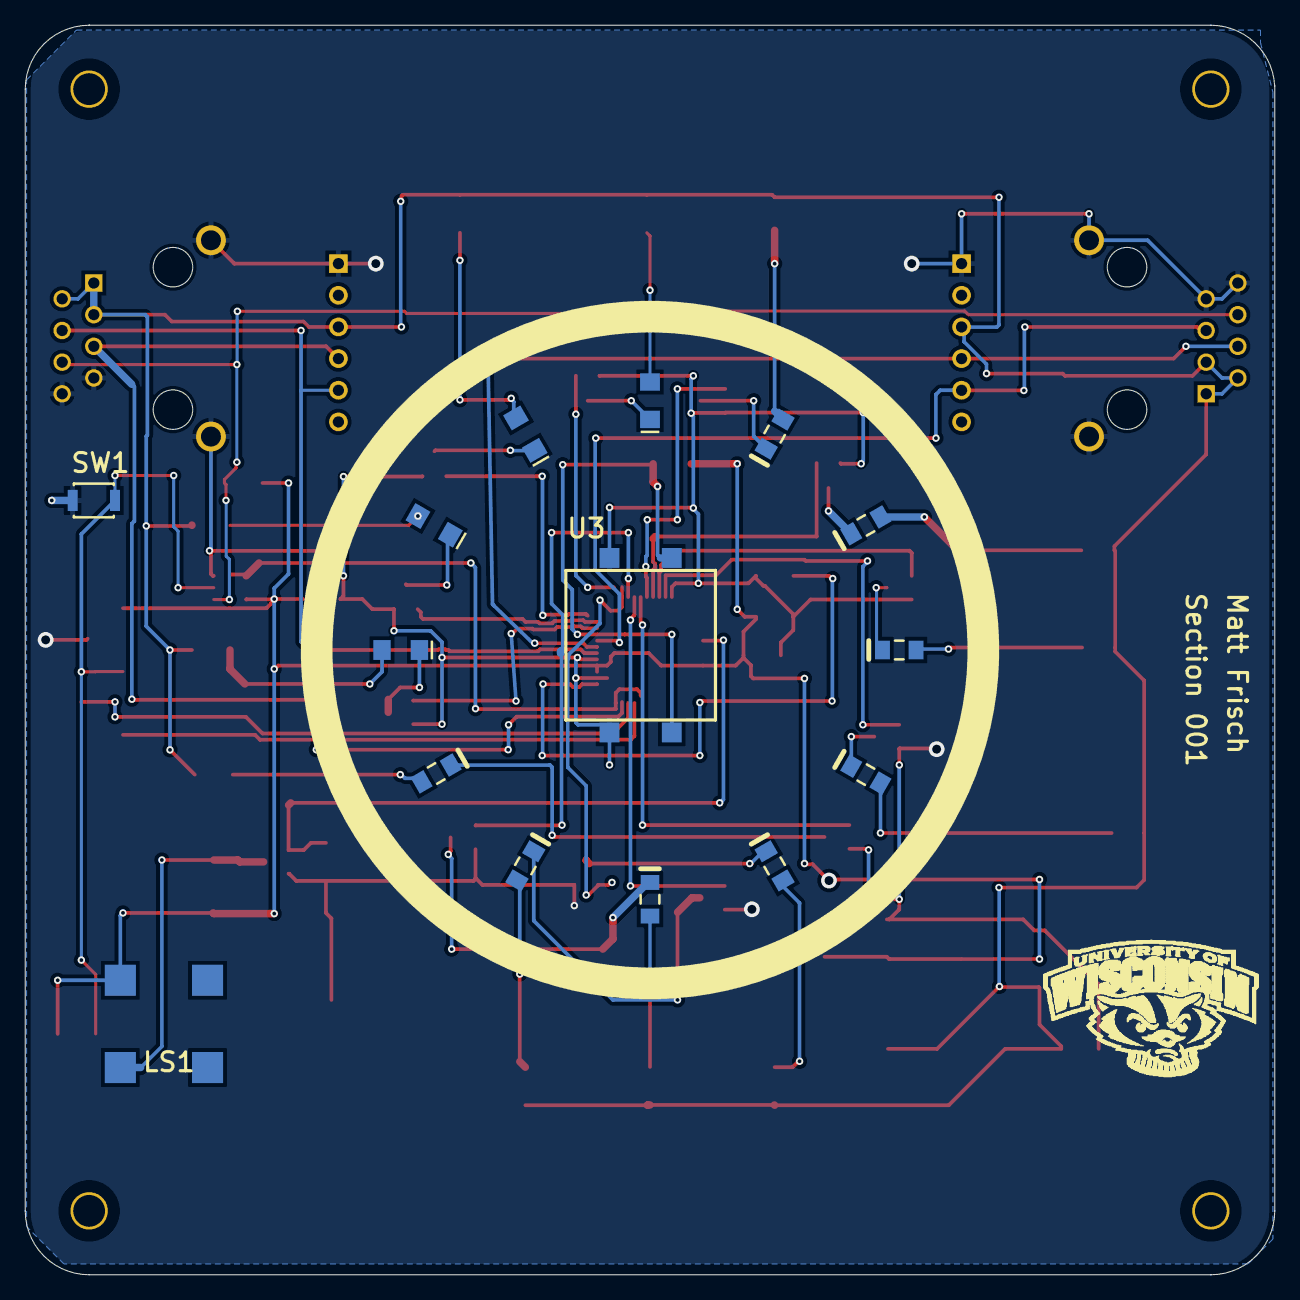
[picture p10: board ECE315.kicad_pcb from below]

Board: 2 copper layers, 100.3 x 100.3 mm, 67 parts (16 on the bottom side), 52 nets.

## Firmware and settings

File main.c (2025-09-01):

/**
 * @file main.c
 * @author Joe Krachey (jkrachey@wisc.edu)
 * @brief
 * @version 0.1
 * @date 2023-10-20
 *
 * @copyright Copyright (c) 2023
 *
 */

#include "drivers/ece315.h"

void turn_LED_on(uint8_t LED, uint8_t delay)
{
    switch (LED)
    {
    case 0:
        cyhal_gpio_write(PIN_LED_R4, LED_ON);
        cyhal_system_delay_ms(delay);
        cyhal_gpio_write(PIN_LED_R4, LED_OFF);
        break;
    case 1:
        cyhal_gpio_write(PIN_LED_R3, LED_ON);
        cyhal_system_delay_ms(delay);
        cyhal_gpio_write(PIN_LED_R3, LED_OFF);
        break;
    case 2:
        cyhal_gpio_write(PIN_LED_R2, LED_ON);
        cyhal_system_delay_ms(delay);
        cyhal_gpio_write(PIN_LED_R2, LED_OFF);
        break;
    case 3:
        cyhal_gpio_write(PIN_LED_R1, LED_ON);
        cyhal_system_delay_ms(delay);
        cyhal_gpio_write(PIN_LED_R1, LED_OFF);
        break;
    case 4:
        cyhal_gpio_write(PIN_LED_Y4, LED_ON);
        cyhal_system_delay_ms(delay);
        cyhal_gpio_write(PIN_LED_Y4, LED_OFF);
        break;
    case 5:
        cyhal_gpio_write(PIN_LED_Y3, LED_ON);
        cyhal_system_delay_ms(delay);
        cyhal_gpio_write(PIN_LED_Y3, LED_OFF);
        break;
    case 6:
        cyhal_gpio_write(PIN_LED_Y2, LED_ON);
        cyhal_system_delay_ms(delay);
        cyhal_gpio_write(PIN_LED_Y2, LED_OFF);
        break;

    case 7:
        cyhal_gpio_write(PIN_LED_Y1, LED_ON);
        cyhal_system_delay_ms(delay);
        cyhal_gpio_write(PIN_LED_Y1, LED_OFF);
        break;
    case 8:
        cyhal_gpio_write(PIN_LED_G4, LED_ON);
        cyhal_system_delay_ms(50);
        cyhal_gpio_write(PIN_LED_G4, LED_OFF);
        break;
    case 9:
        cyhal_gpio_write(PIN_LED_G3, LED_ON);
        cyhal_system_delay_ms(50);
        cyhal_gpio_write(PIN_LED_G3, LED_OFF);
        break;
    case 10:
        cyhal_gpio_write(PIN_LED_G2, LED_ON);
        cyhal_system_delay_ms(50);
        cyhal_gpio_write(PIN_LED_G2, LED_OFF);
        break;
    case 11:
        cyhal_gpio_write(PIN_LED_G1, LED_ON);
        cyhal_system_delay_ms(50);
        cyhal_gpio_write(PIN_LED_G1, LED_OFF);
        break;
    default:
        break;
    }
}

int main(void)
{
    bool buzzer_on = false;
    bool status_rx_upstream = false;
    bool status_rx_downstream = false;
    bool game_over;
    bool active_LED_on;
    uint8_t upstream_msg[80];
    uint8_t downstream_msg[80];
    uint8_t delay;
    /* Enable global interrupts */
    __enable_irq();

    /* Enable the button*/
    ece315_button_init();

    /* Enable LEDs */
    ece315_leds_init();

    // Turn LEDS off
    ece315_leds_all_off();

    /* Initialize the Buzzer to operate at 2.5KHz */
    ece315_buzzer_init(2500);

    for (;;)
    {

        game_over = true;

        if (ALERT_BUTTON_PRESSED)
        {
            game_over = false;
            ALERT_BUTTON_PRESSED = false;
        }

        delay = 50;
        uint8_t i;
        while (game_over == false)
        {
            i++;
            if (i == 12)
            {
                i = 0;
            }
            turn_LED_on(i, delay);
            if ((i == 8) || (i == 9) || (i == 10) || (i == 11))
            {
                active_LED_on = true;
            }
            else
            {
                active_LED_on = false;
            }
            if (active_LED_on && ALERT_BUTTON_PRESSED)
            {
                delay -= 5;
                buzzer_on = true;
                if (buzzer_on)
                {
                    ece315_buzzer_start();
                    cyhal_system_delay_ms(100);
                    ece315_buzzer_stop();
                    buzzer_on = false;
                }
                ALERT_BUTTON_PRESSED = false;
            }
            else if ((active_LED_on == false) && ALERT_BUTTON_PRESSED)
            {
                game_over = true;
                ALERT_BUTTON_PRESSED = false;
            }
        }

        if (game_over)
        {
            if (ALERT_LEDS_OFF)
            {
                ALERT_LEDS_OFF = false;
                ece315_leds_all_off();
            }

            if (ALERT_LEDS_ON)
            {
                ALERT_LEDS_ON = false;
                ece315_leds_all_on();
            }
        }
    }
}

/* [] END OF FILE */

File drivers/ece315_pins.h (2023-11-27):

/**
 * @file ece315_pins.h
 * @author Joe Krachey (jkrachey@wisc.edu)
 * @brief 
 * @version 0.1
 * @date 2023-11-01
 * 
 * @copyright Copyright (c) 2023
 * 
 */

#ifndef __ECE315_PINS_H__
#define __ECE315_PINS_H__

/* If you are using your own board, you will need to
 * change the define below to be:
 *  #undef ECE315_STAFF_BOARD
 * 
 * You will then need to define each of the following MACROs to 
 * match the pins you used when designing your version of the board
 */
#define ECE315_STAFF_BOARD

#ifdef ECE315_STAFF_BOARD

/* UART - Down Stream*/
#define PIN_UART_DOWN_RX    P1_0
#define PIN_UART_DOWN_TX    P1_1

/* UART - Up Stream*/
#define PIN_UART_UP_RX      P0_4
#define PIN_UART_UP_TX      P0_5

/* LEDs - Green*/
#define PIN_LED_G1          P4_3
#define PIN_LED_G2          P4_2
#define PIN_LED_G3          P4_1
#define PIN_LED_G4          P4_0

/* LEDs - Red*/
#define PIN_LED_R1          P1_6
#define PIN_LED_R2          P1_5
#define PIN_LED_R3          P1_4
#define PIN_LED_R4          P1_3

/* LEDs - Yellow*/
#define PIN_LED_Y1          P3_0
#define PIN_LED_Y2          P2_7
#define PIN_LED_Y3          P2_1
#define PIN_LED_Y4          P2_0

/*Buzzer*/
#define PIN_BUZZER          P3_4

/*Button*/
#define PIN_BTN             P0_2

#else

/* Define each of the following pins based on the pins you 
 * selected for your version of the ECE315 board
 */

/* UART - Down Stream*/
#define PIN_UART_DOWN_RX    P0_0
#define PIN_UART_DOWN_TX    P0_0

/* UART - Up Stream*/
#define PIN_UART_UP_RX      P0_0
#define PIN_UART_UP_TX      P0_0

/* LEDs - Green*/
#define PIN_LED_G1          P0_0
#define PIN_LED_G2          P0_0
#define PIN_LED_G3          P0_0
#define PIN_LED_G4          P0_0

/* LEDs - Red*/
#define PIN_LED_R1          P0_0
#define PIN_LED_R2          P0_0
#define PIN_LED_R3          P0_0
#define PIN_LED_R4          P0_0

/* LEDs - Yellow*/
#define PIN_LED_Y1          P0_0
#define PIN_LED_Y2          P0_0
#define PIN_LED_Y3          P0_0
#define PIN_LED_Y4          P0_0

/*Buzzer*/
#define PIN_BUZZER          P0_0

/*Button*/
#define PIN_BTN             P0_0

#endif

#endif

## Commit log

2023-11-27 Removing interrupts.c and .h files
2025-09-01 added pcb files
    [01-Revision_History_and_Contents.kicad_sch, 02-UART.kicad_sch, 03-LED-GREEN.kicad_sch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]
